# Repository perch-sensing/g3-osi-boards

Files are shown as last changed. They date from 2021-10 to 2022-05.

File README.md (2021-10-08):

# Perch 3GRMC Platform

## Getting Started

You'll want to clone this repo with an `ssh` key. To setup an `ssh` key on
GitHub, follow this [link](https://docs.github.com/en/github/authenticating-to-github/connecting-to-github-with-ssh).

Additionally, this README assumes that you are using Visual Studio Code.

### HW/SW

You need to initialize the various submodules with the following command:

```shell
git submodule update --init --recursive
```

The submodules include the Perch kicad library as well as micropython libraries.

### Hardware

The hardware is designed using KiCad 5.X. You will need to download KiCad from
[https://kicad.org/download/](https://kicad.org/download/).

To work with KiCad files in a Git repository, certain parts of the file should
be ignored. To ignore these commands in git, you can add to the project-local
config. To facilitate this, a `.gitconfig` file has been provided in this
repository. To use the provided `.gitconfig` file, you need to add it to the
project config.

Run the following command:

```shell
git config --local include.path ../.gitconfig
```

Next, you'll want to install `plotkicadsch` to your path. You can download
the binary [here](https://github.com/jnavila/plotkicadsch/releases). For
assistance in adding a folder to your path, visit
[this](https://www.howtogeek.com/118594/how-to-edit-your-system-path-for-easy-command-line-access/) link.

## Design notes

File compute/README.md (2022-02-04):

Here is a link to the Compute BOM:
https://docs.google.com/spreadsheets/d/1j4ZL0j2LjKp-IoZsxxflOpX7Q5H--Hl_RDHMVLFPHzU/edit#gid=0

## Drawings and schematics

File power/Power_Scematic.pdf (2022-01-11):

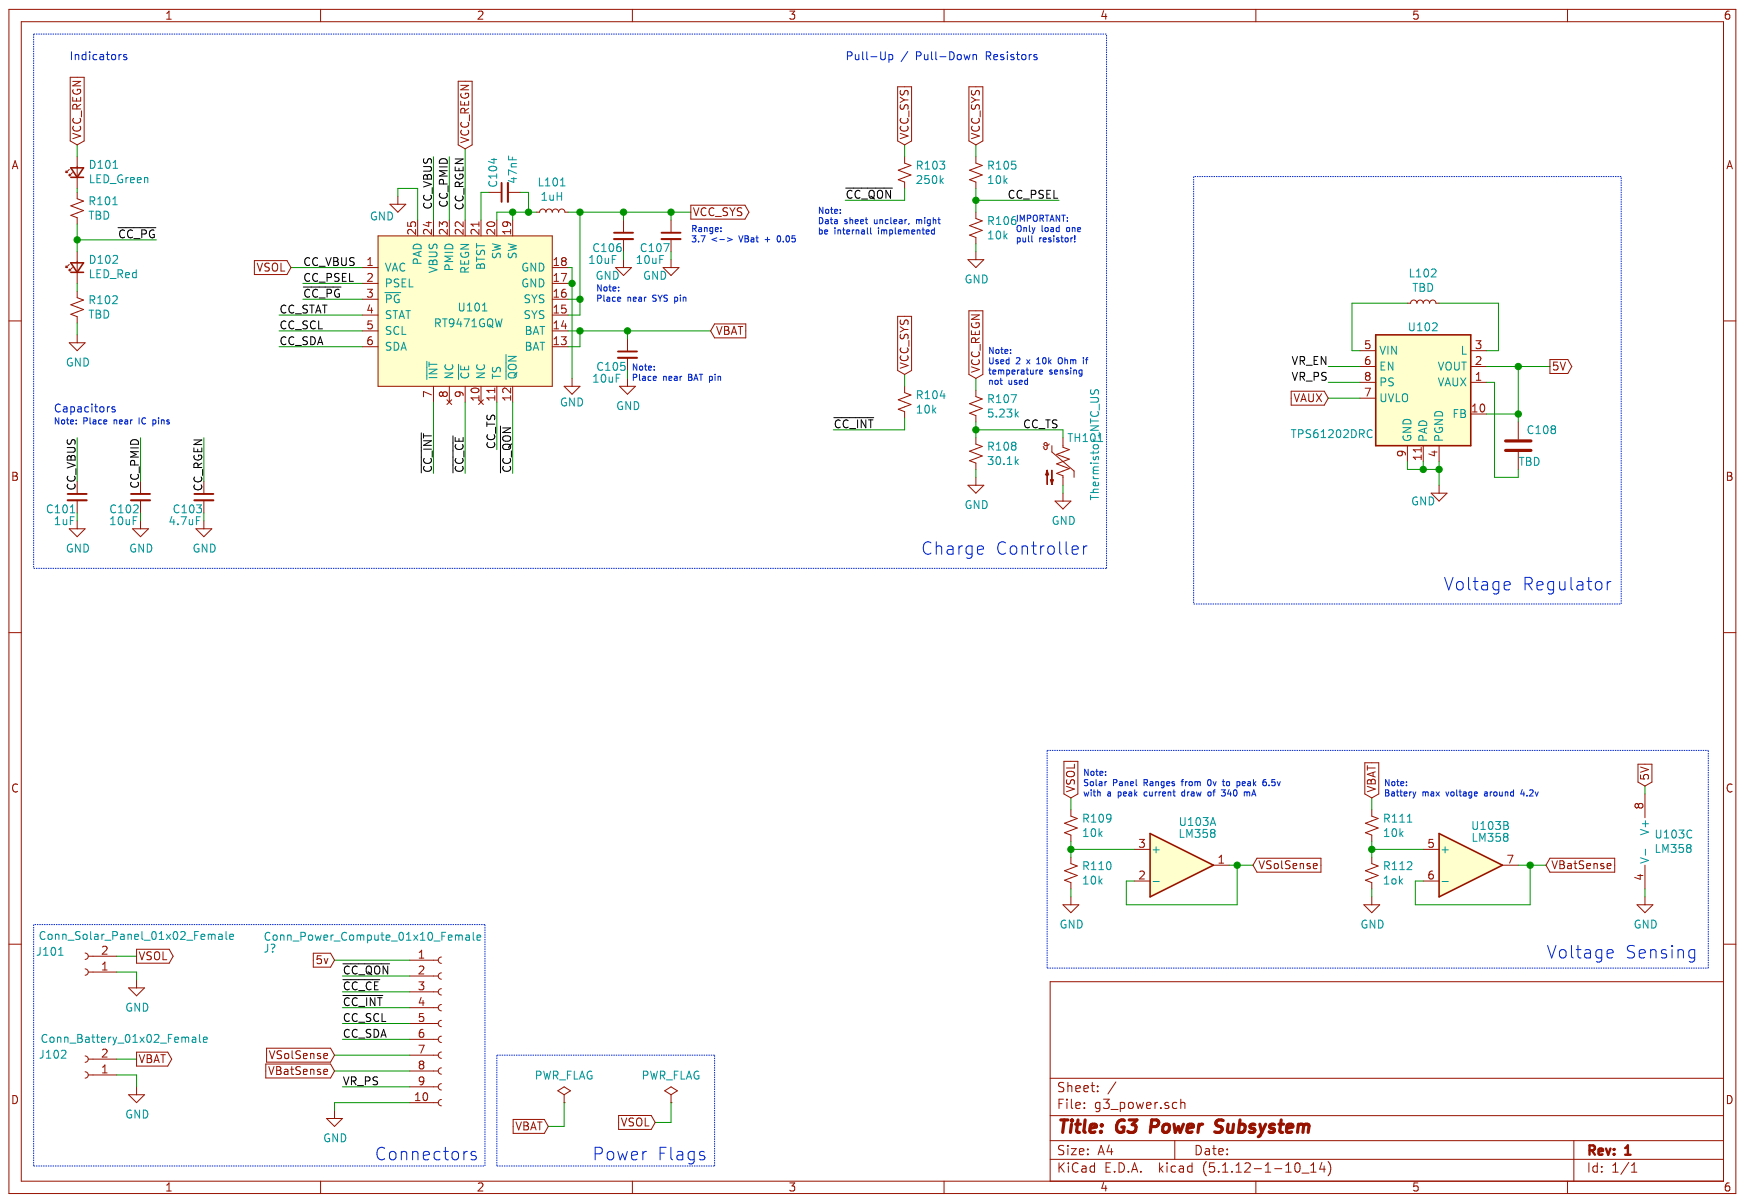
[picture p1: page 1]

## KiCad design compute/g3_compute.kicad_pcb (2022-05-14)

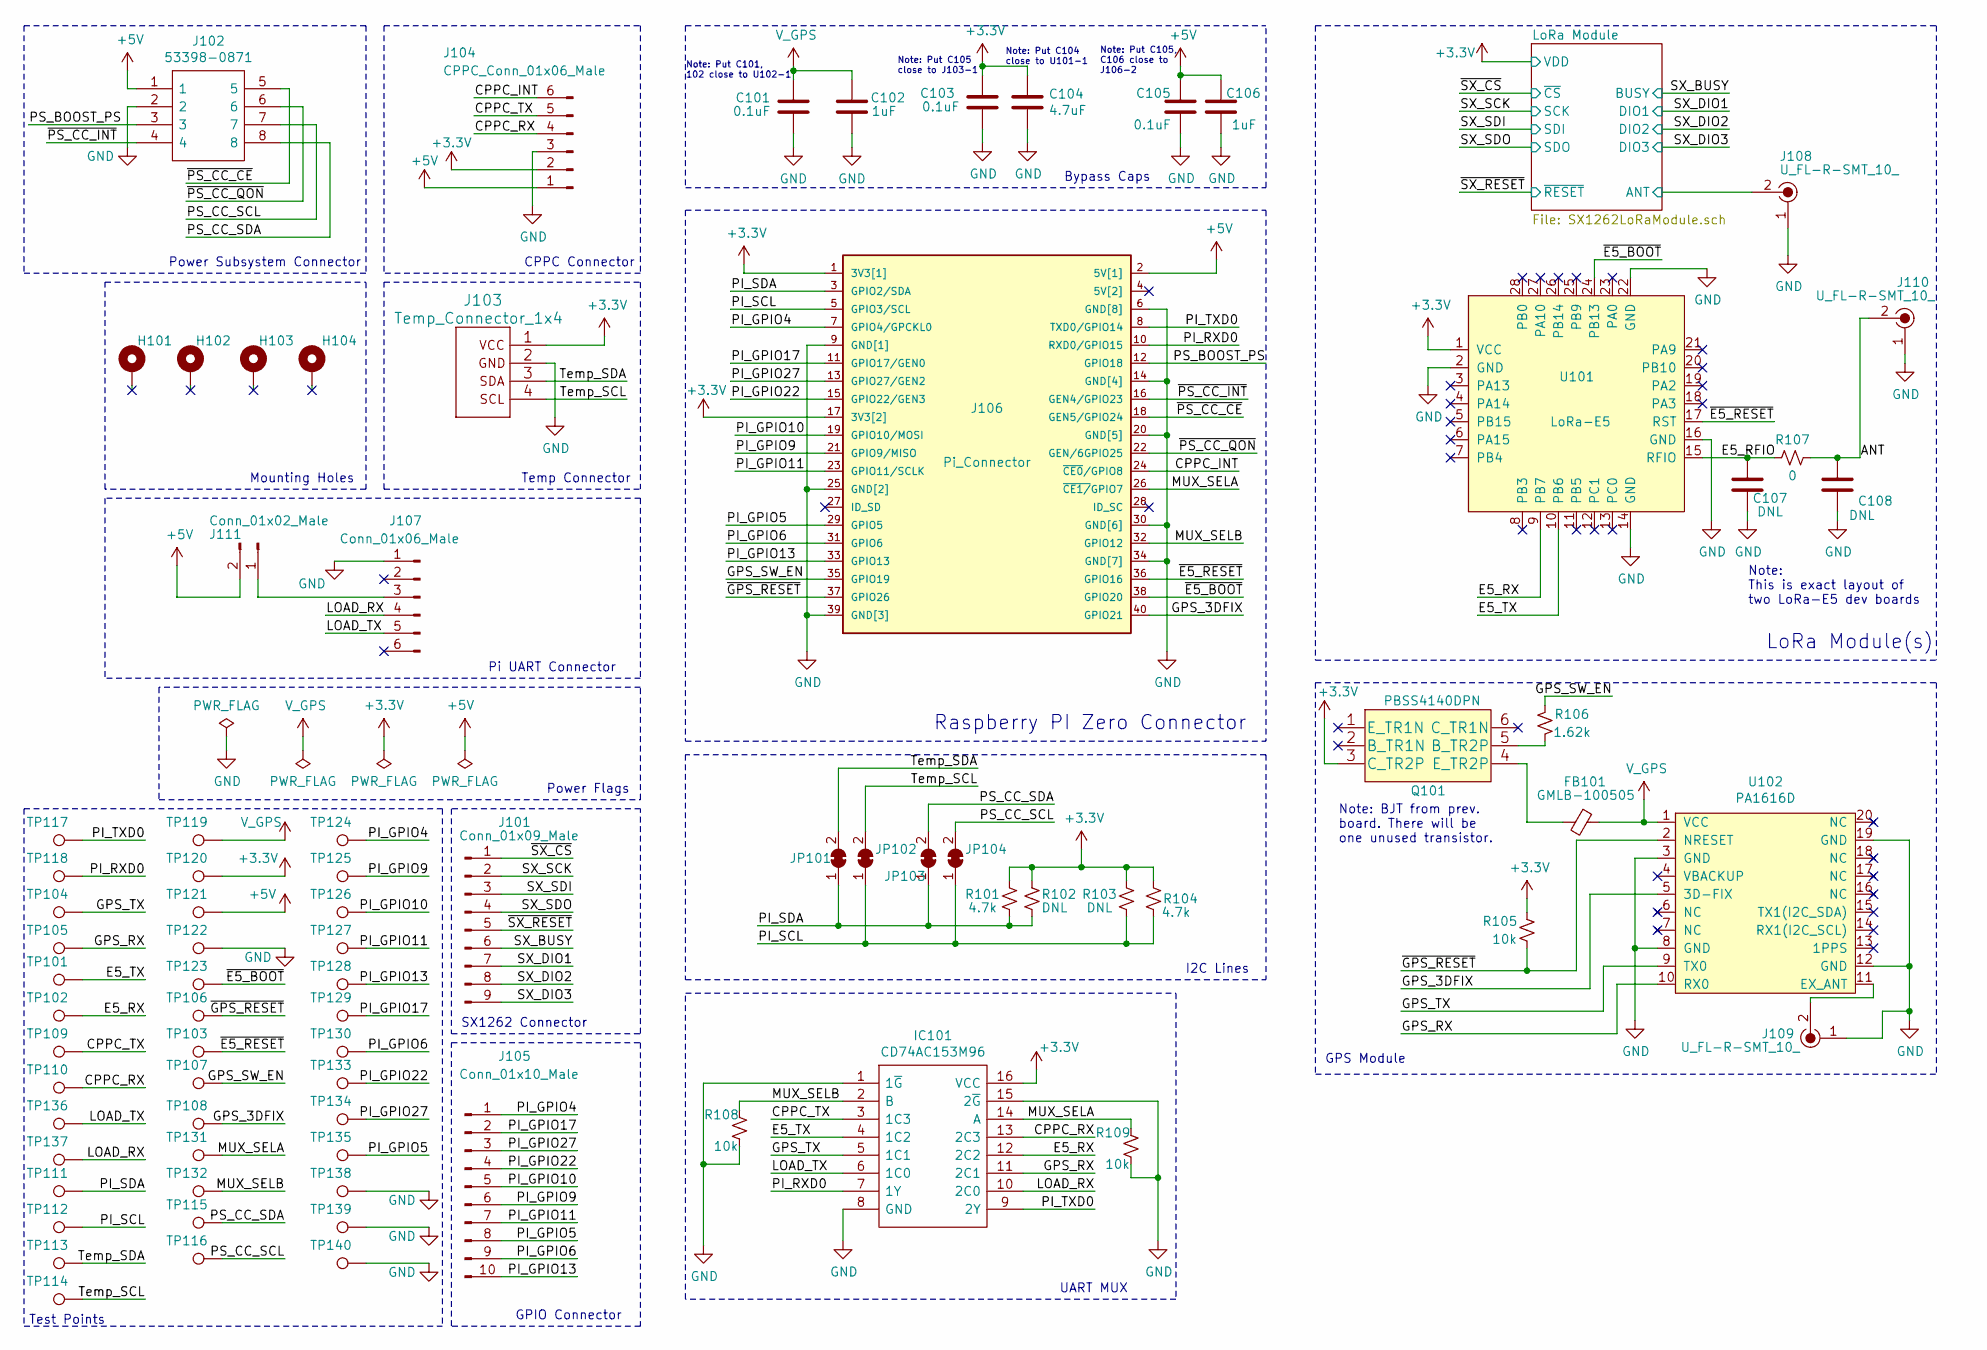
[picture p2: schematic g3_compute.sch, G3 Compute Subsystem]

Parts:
C101, C103, C105: 0.1uF; C_0402_1005Metric_Pad0.74x0.62mm_HandSolder
C102, C106: 1uF; C_0402_1005Metric_Pad0.74x0.62mm_HandSolder
C104: 4.7uF; C_0402_1005Metric_Pad0.74x0.62mm_HandSolder
C107, C108: DNL; C_0402_1005Metric_Pad0.74x0.62mm_HandSolder
FB101: GMLB-100505; R_0402_1005Metric_Pad0.72x0.64mm_HandSolder
H101, H102, H103, H104: MountingHole_Pad; MountingHole_2.5mm_Pad
IC101: CD74AC153M96; SOIC127P600X175-16N_MUX; Mouser Part Number 595-CD74AC153M96
J101: Conn_01x09_Male; PinHeader_1x09_P2.54mm_Vertical
J102: 53398-0871; 53398-0871_Molex
J103: Temp_Connector_1x4; 1702474_Temp_Sensor_Connector
J104: CPPC_Conn_01x06_Male; PinHeader_1x06_P2.54mm_Vertical_SMD_Pin1Left
J105: Conn_01x10_Male; PinHeader_1x10_P2.54mm_Vertical
J106: Pi_Connector; ADA3708_RaspPiZero; Manufacturer_Part_Number 2885
J107: Conn_01x06_Male; PinHeader_1x06_P2.54mm_Vertical
J108, J109, J110: U_FL-R-SMT_10_; Coax_Conn_U.FL; MPN U.FL-R-SMT(10); Digi-Key_PN H9161CT-ND
J111: Conn_01x02_Male; PinHeader_1x02_P2.54mm_Vertical_SMD_Pin1Left
JP101, JP102, JP103, JP104: SolderJumper_2_Bridged; SolderJumper-2_P1.3mm_Bridged_RoundedPad1.0x1.5mm
Q101: PBSS4140DPN
R101, R104: 4.7k; R_0402_1005Metric_Pad0.72x0.64mm_HandSolder
R102, R103: DNL; R_0402_1005Metric_Pad0.72x0.64mm_HandSolder
R105, R108, R109: 10k; R_0402_1005Metric_Pad0.72x0.64mm_HandSolder
R106: 1.62k; R_0603_1608Metric_Pad0.98x0.95mm_HandSolder
R107: 0; R_0402_1005Metric_Pad0.72x0.64mm_HandSolder
TP101, TP102, TP103, TP104, TP105, TP106, TP107, TP108, TP109, TP110, TP111, TP112, TP113, TP114, TP115, TP116, TP117, TP118, TP119, TP120, TP121, TP122, TP123, TP124, TP125, TP126, TP127, TP128, TP129, TP130, TP131, TP132, TP133, TP134, TP135, TP136, TP137, TP138, TP139, TP140: TestPoint; HARWIN_S2751-46R
U101: LoRa-E5
U102: PA1616D; PA1616D_GPS

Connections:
+3V3: C103.2, C104.1, IC101.16 (VCC), J103.1 (Vdd), J104.2, J106.1 (3V3[1]), J106.17 (3V3[2]), Q101.3 (C_TR2P), R101.2, R102.2, R103.2, R104.2, R105.2, TP120.1, U101.1 (VCC); also elsewhere on the board
+5V: C105.2, C106.2, J102.1, J104.1, J106.2 (5V[1]), J111.2, TP121.1
/ANT: C108.1, J110.2, R107.2
/CPPC_INT: J104.6, J106.24 (~CE0~/GPIO8)
/CPPC_RX: IC101.13 (2C3), J104.4, TP110.1
/CPPC_TX: IC101.3 (1C3), J104.5, TP109.1
/E5_RFIO: C107.1, R107.1, U101.15 (RFIO)
/E5_RX: IC101.12 (2C2), TP102.1, U101.9 (PB7)
/E5_TX: IC101.4 (1C2), TP101.1, U101.10 (PB6)
/GPS_3DFIX: J106.40 (GPIO21), TP108.1, U102.5 (3D-FIX)
/GPS_RX: IC101.11 (2C1), TP105.1, U102.10 (RX0)
/GPS_SW_EN: J106.35 (GPIO19), R106.2, TP107.1
/GPS_TX: IC101.5 (1C1), TP104.1, U102.9 (TX0)
/LOAD_RX: IC101.10 (2C0), J107.4, TP137.1
/LOAD_TX: IC101.6 (1C0), J107.5, TP136.1
/LoRa Module/ANT: J108.2; also elsewhere on the board
/MUX_SELA: IC101.14 (A), J106.26 (~CE1/~GPIO7), R109.2, TP131.1
/MUX_SELB: IC101.2 (B), J106.32 (GPIO12), R108.2, TP132.1
/PI_GPIO4: J105.1, J106.7 (GPIO4/GPCKL0), TP124.1
/PI_GPIO5: J105.8, J106.29 (GPIO5), TP135.1
/PI_GPIO6: J105.9, J106.31 (GPIO6), TP130.1
/PI_GPIO9: J105.6, J106.21 (GPIO9/MISO), TP125.1
/PI_GPIO10: J105.5, J106.19 (GPIO10/MOSI), TP126.1
/PI_GPIO11: J105.7, J106.23 (GPIO11/SCLK), TP127.1
/PI_GPIO13: J105.10, J106.33 (GPIO13), TP128.1
/PI_GPIO17: J105.2, J106.11 (GPIO17/GEN0), TP129.1
/PI_GPIO22: J105.4, J106.15 (GPIO22/GEN3), TP133.1
/PI_GPIO27: J105.3, J106.13 (GPIO27/GEN2), TP134.1
/PI_RXD0: IC101.7 (1Y), J106.10 (RXD0/GPIO15), TP118.1
/PI_SCL: J106.5 (GPIO3/SCL), JP102.1 (A), JP104.1 (A), R103.1, R104.1, TP112.1
/PI_SDA: J106.3 (GPIO2/SDA), JP101.1 (A), JP103.1 (A), R101.1, R102.1, TP111.1
/PI_TXD0: IC101.9 (2Y), J106.8 (TXD0/GPIO14), TP117.1
/PS_BOOST_PS: J102.3, J106.12 (GPIO18)
/PS_CC_SCL: J102.7, JP104.2 (B), TP116.1
/PS_CC_SDA: J102.8, JP103.2 (B), TP115.1
/SX_BUSY: J101.6; also elsewhere on the board
/SX_DIO1: J101.7; also elsewhere on the board
/SX_DIO2: J101.8; also elsewhere on the board
/SX_DIO3: J101.9; also elsewhere on the board
/SX_SCK: J101.2; also elsewhere on the board
/SX_SDI: J101.3; also elsewhere on the board
/SX_SDO: J101.4; also elsewhere on the board
/Temp_SCL: J103.4 (SCL), JP102.2 (B), TP114.1
/Temp_SDA: J103.3 (SDA), JP101.2 (B), TP113.1
/~E5_BOOT: J106.38 (GPIO20), TP123.1, U101.24 (PB13~)
/~E5_RESET: J106.36 (GPIO16), TP103.1, U101.17 (RST)
/~GPS_RESET: J106.37 (GPIO26), R105.1, TP106.1, U102.2 (NRESET)
/~PS_CC_CE: J102.5, J106.18 (GEN5/GPIO24)
/~PS_CC_INT: J102.4, J106.16 (GEN4/GPIO23)
/~PS_CC_QON: J102.6, J106.22 (GEN/6GPIO25)
/~SX_CS: J101.1; also elsewhere on the board
/~SX_RESET: J101.5; also elsewhere on the board
GND: C101.1, C102.1, C103.1, C104.2, C105.1, C106.1, C107.2, C108.2, IC101.1 (1~G), IC101.8 (GND), IC101.15 (2~G), J102.2, J103.2 (Gnd), J104.3, J106.6 (GND[8]), J106.9 (GND[1]), J106.14 (GND[4]), J106.20 (GND[5]), J106.25 (GND[2]), J106.30 (GND[6]), J106.34 (GND[7]), J106.39 (GND[3]), J107.1, J108.1, J109.1, J110.1, R108.1, R109.1, TP122.1, TP138.1, TP139.1, TP140.1, U101.2 (GND), U101.14 (GND), U101.16 (GND), U101.22 (GND), U102.3 (GND), U102.8 (GND), U102.12 (GND), U102.19 (GND); also elsewhere on the board
unnamed: FB101.2, Q101.4 (E_TR2P)
unnamed: J107.3, J111.1
unnamed: J109.2, U102.11 (EX_ANT)
unnamed: Q101.5 (B_TR2P), R106.1
V_GPS: C101.2, C102.2, FB101.1, TP119.1, U102.1 (VCC)

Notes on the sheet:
Power Subsystem Connector
Mounting Holes
SX1262 Connector
GPIO Connector
GPS Module
Note: BJT from prev. board. There will be one unused transistor.
Note: This is exact layout of two LoRa-E5 dev boards
Note: Put C101, 102 close to U102-1
Note: Put C105 close to J103-1
Pi UART Connector
Note: Put C105, C106 close to J106-2
Bypass Caps
Raspberry PI Zero Connector
LoRa Module(s)
Temp Connector
CPPC Connector
I2C Lines
Test Points
UART MUX
Power Flags
Note: Put C104 close to U101-1

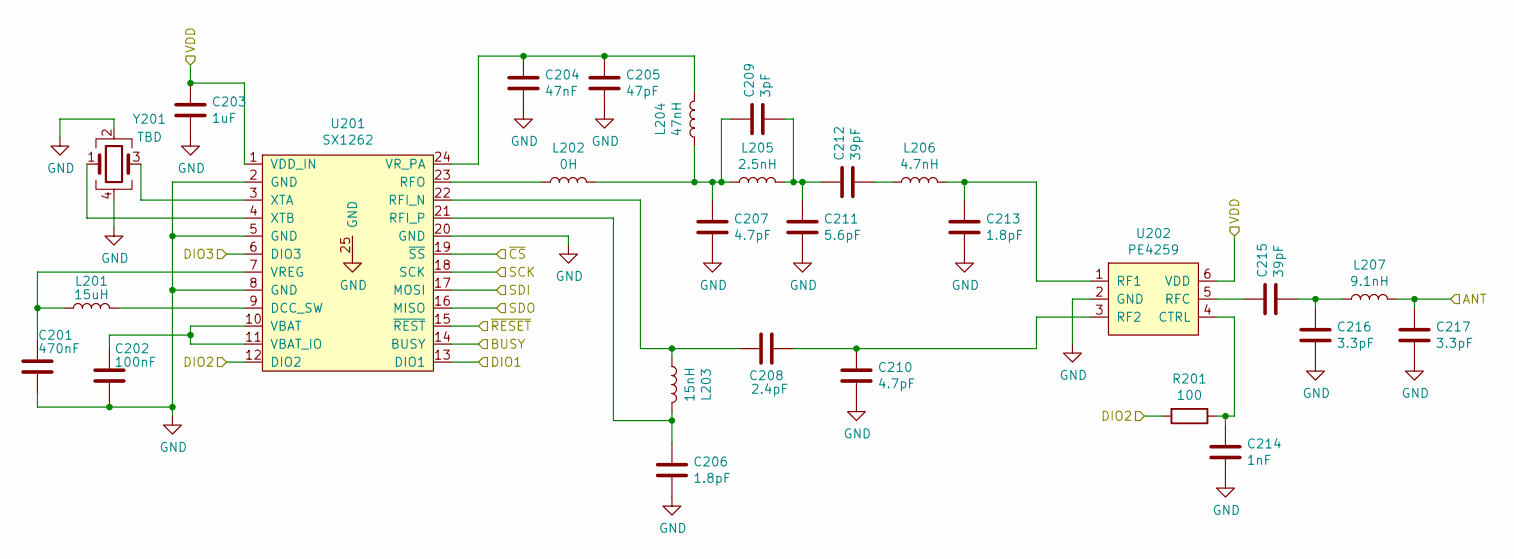
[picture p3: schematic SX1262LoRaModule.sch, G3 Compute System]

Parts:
C201: 470nF; C_0402_1005Metric_Pad0.74x0.62mm_HandSolder
C202: 100nF; C_0402_1005Metric_Pad0.74x0.62mm_HandSolder
C203: 1uF; C_0402_1005Metric_Pad0.74x0.62mm_HandSolder
C204: 47nF; C_0402_1005Metric_Pad0.74x0.62mm_HandSolder
C205: 47pF; C_0402_1005Metric_Pad0.74x0.62mm_HandSolder
C206, C213: 1.8pF; C_0402_1005Metric_Pad0.74x0.62mm_HandSolder
C207, C210: 4.7pF; C_0402_1005Metric_Pad0.74x0.62mm_HandSolder
C208: 2.4pF; C_0402_1005Metric_Pad0.74x0.62mm_HandSolder
C209: 3pF; C_0402_1005Metric_Pad0.74x0.62mm_HandSolder
C211: 5.6pF; C_0402_1005Metric_Pad0.74x0.62mm_HandSolder
C212, C215: 39pF; C_0402_1005Metric_Pad0.74x0.62mm_HandSolder
C214: 1nF; C_0402_1005Metric_Pad0.74x0.62mm_HandSolder
C216, C217: 3.3pF; C_0402_1005Metric_Pad0.74x0.62mm_HandSolder
L201: 15uH; L_0805_2012Metric_Pad1.05x1.20mm_HandSolder
L202: 0H; L_0402_1005Metric_Pad0.77x0.64mm_HandSolder
L203: 15nH; L_0402_1005Metric_Pad0.77x0.64mm_HandSolder
L204: 47nH; L_0402_1005Metric_Pad0.77x0.64mm_HandSolder
L205: 2.5nH; L_0402_1005Metric_Pad0.77x0.64mm_HandSolder
L206: 4.7nH; L_0402_1005Metric_Pad0.77x0.64mm_HandSolder
L207: 9.1nH; L_0402_1005Metric_Pad0.77x0.64mm_HandSolder
R201: 100; R_0402_1005Metric_Pad0.72x0.64mm_HandSolder
U201: SX1262; QFN-24-1EP_4x4mm_P0.5mm_EP2.7x2.7mm
U202: PE4259; SOT-363_SC-70-6
Y201: TBD; Crystal_SMD_2016-4Pin_2.0x1.6mm

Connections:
+3V3: C203.1, U201.1 (VDD_IN), U202.6 (VDD); also elsewhere on the board
/LoRa Module/ANT: C217.1, L207.2; also elsewhere on the board
/SX_BUSY: U201.14 (BUSY); also elsewhere on the board
/SX_DIO1: U201.13 (DIO1); also elsewhere on the board
/SX_DIO2: R201.2, U201.12 (DIO2); also elsewhere on the board
/SX_DIO3: U201.6 (DIO3); also elsewhere on the board
/SX_SCK: U201.18 (SCK); also elsewhere on the board
/SX_SDI: U201.17 (MOSI); also elsewhere on the board
/SX_SDO: U201.16 (MISO); also elsewhere on the board
/~SX_CS: U201.19 (~SS); also elsewhere on the board
/~SX_RESET: U201.15 (~REST); also elsewhere on the board
GND: C201.2, C202.2, C203.2, C204.2, C205.2, C206.2, C207.2, C210.2, C211.2, C213.2, C214.2, C216.2, C217.2, U201.2 (GND), U201.5 (GND), U201.8 (GND), U201.20 (GND), U201.25 (GND), U202.2 (GND), Y201.2, Y201.4; also elsewhere on the board
unnamed: C201.1, L201.1, U201.7 (VREG)
unnamed: C202.1, U201.10 (VBAT), U201.11 (VBAT_IO)
unnamed: C204.1, C205.1, L204.2, U201.24 (VR_PA)
unnamed: C206.1, L203.2, U201.21 (RFI_P)
unnamed: C207.1, C209.1, L202.2, L204.1, L205.1
unnamed: C208.1, L203.1, U201.22 (RFI_N)
unnamed: C208.2, C210.1, U202.3 (RF2)
unnamed: C209.2, C211.1, C212.1, L205.2
unnamed: C212.2, L206.1
unnamed: C213.1, L206.2, U202.1 (RF1)
unnamed: C214.1, R201.1, U202.4 (CTRL)
unnamed: C215.1, U202.5 (RFC)
unnamed: C215.2, C216.1, L207.1
unnamed: L201.2, U201.9 (DCC_SW)
unnamed: L202.1, U201.23 (RFO)
unnamed: U201.3 (XTA), Y201.3
unnamed: U201.4 (XTB), Y201.1

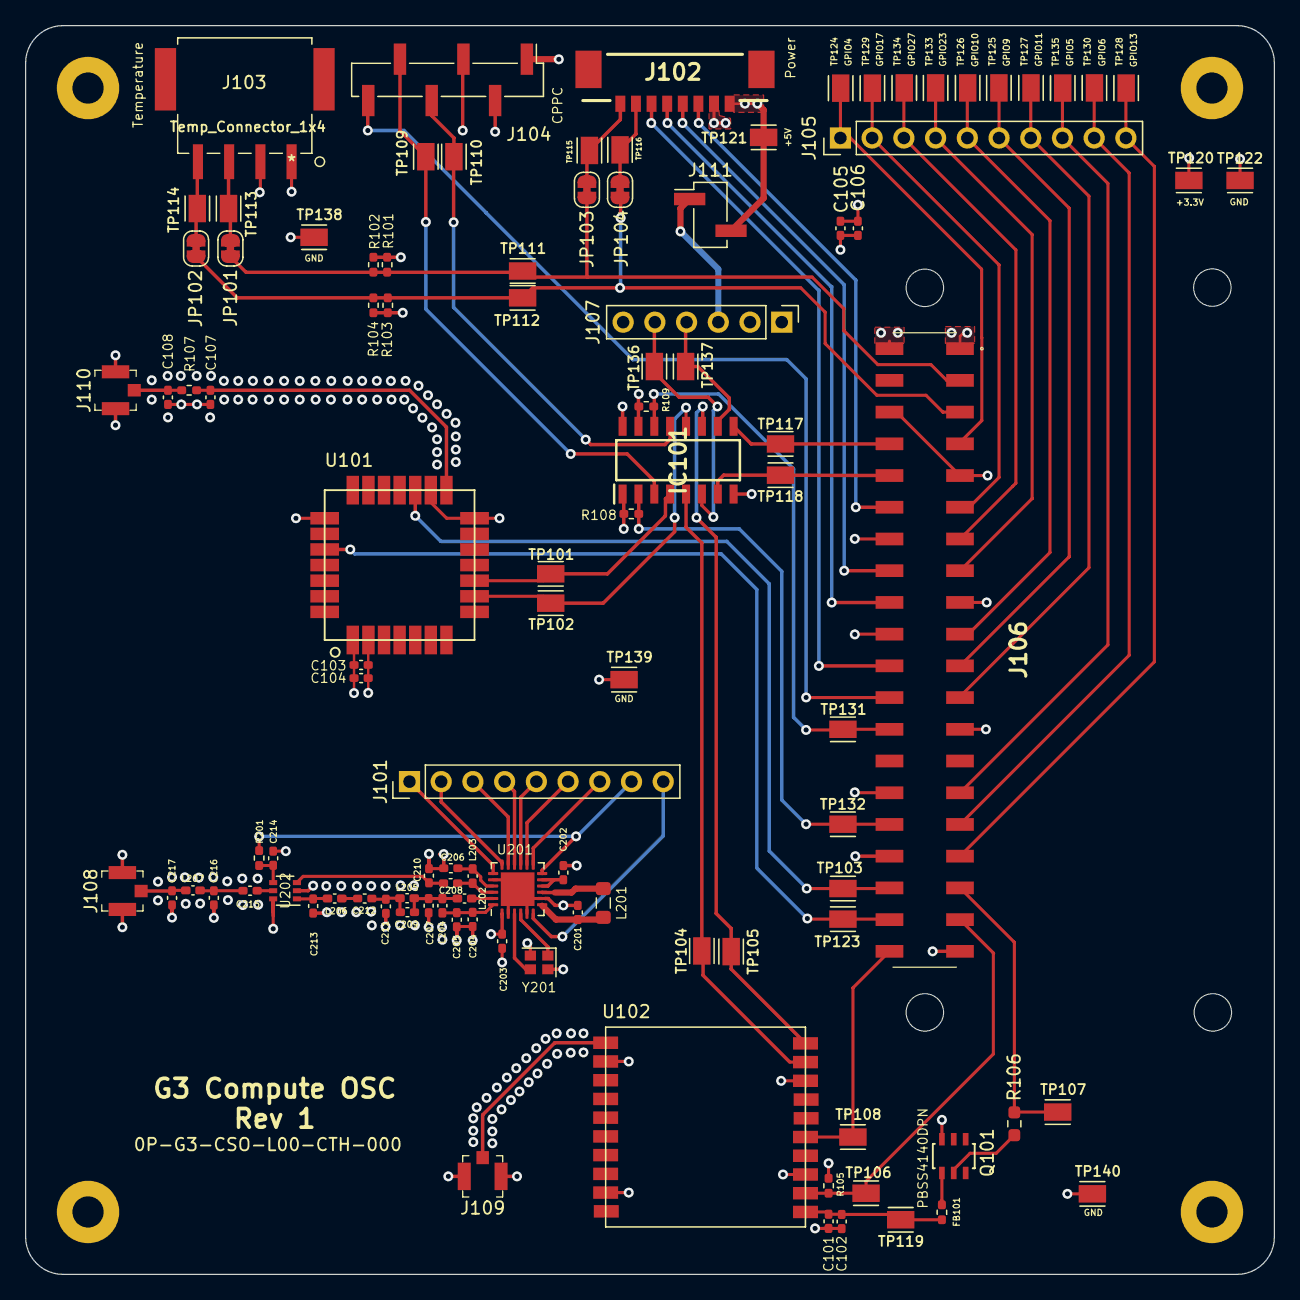
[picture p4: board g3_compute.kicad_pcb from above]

Board: 4 copper layers, 100.0 x 100.0 mm, 109 parts (0 on the bottom side), 75 nets.

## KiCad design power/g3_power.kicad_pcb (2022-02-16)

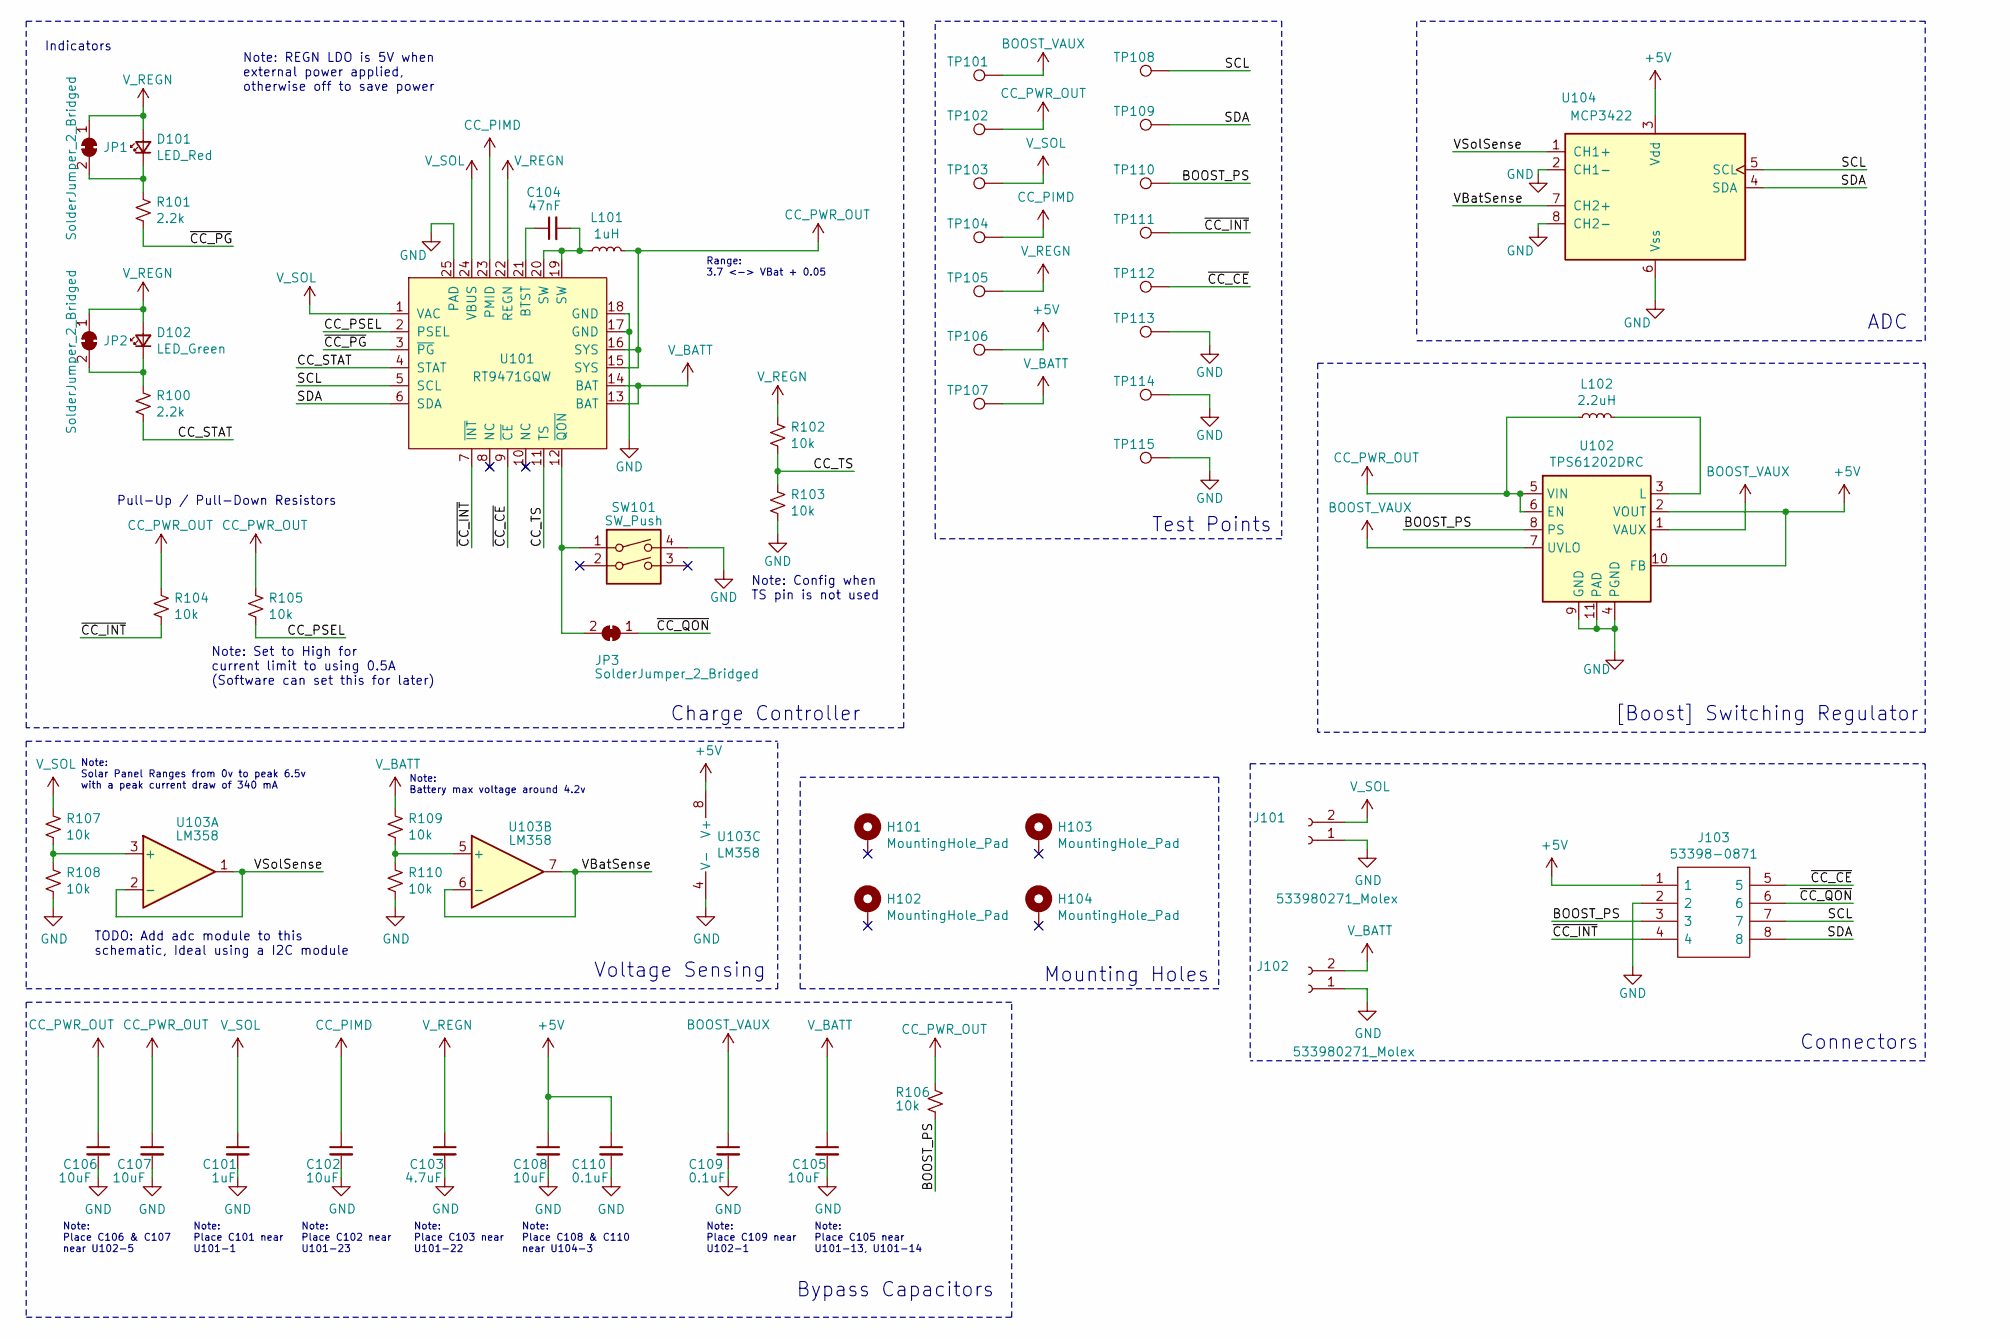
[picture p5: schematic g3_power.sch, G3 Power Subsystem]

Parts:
C101: 1uF; C_0402_1005Metric_Pad0.74x0.62mm_HandSolder; Manufacturer_Part_Number CC0402MRX5R6BB105
C102, C105, C106, C107, C108: 10uF; C_0402_1005Metric_Pad0.74x0.62mm_HandSolder; Manufacturer_Part_Number CAP CER 10000PF 16V X7R 0402
C103: 4.7uF; C_0402_1005Metric_Pad0.74x0.62mm_HandSolder; Manufacturer_Part_Number CC0402MRX5R6BB475
C104: 47nF; C_0805_2012Metric_Pad1.18x1.45mm_HandSolder; Manufacturer_Part_Number CL21B473KCCWPNC
C109, C110: 0.1uF; C_0402_1005Metric_Pad0.74x0.62mm_HandSolder; Manufacturer_Part_Number CC0402JRX7R7BB104
D101: LED_Red; LED_0402_1005Metric_Pad0.77x0.64mm_HandSolder; Manufacturer_Part_Number SML-LX0402SIC-TR
D102: LED_Green; LED_0402_1005Metric_Pad0.77x0.64mm_HandSolder; Manufacturer_Part_Number SML-LX0402SUGC-TR
H101, H102, H103, H104: MountingHole_Pad; MountingHole_2.5mm_Pad
J101, J102: 533980271_Molex; 532610271_Molex; Manufacturer_Part_Number 532610271
J103: 53398-0871; 53398-0871_Molex; Mouser Part Number 538-53398-0871
JP1, JP2, JP3: SolderJumper_2_Bridged; SolderJumper-2_P1.3mm_Bridged_RoundedPad1.0x1.5mm
L101: 1uH; L_1008_2520Metric_Pad1.43x2.20mm_HandSolder; Manufacturer_Part_Number CIGT252010LM1R0MNE
L102: 2.2uH; L_0805_2012Metric_Pad1.15x1.40mm_HandSolder; Manufacturer_Part_Number CIGT201610LH2R2MNE
R100, R101: 2.2k; R_0402_1005Metric_Pad0.72x0.64mm_HandSolder; Manufacturer_Part_Number RC0402JR-072K2L
R102, R103, R104, R105, R106, R107, R108, R109, R110: 10k; R_0402_1005Metric_Pad0.72x0.64mm_HandSolder; Manufacturer_Part_Number RC0402JR-0710KL
SW101: SW_Push; Switch_Tactile_SMD_6x6mm_PTS645; Manufacturer_Part_Number PTS645SH43SMTR92 LFS
TP101, TP102, TP103, TP104, TP105, TP106, TP107, TP108, TP109, TP110, TP111, TP112, TP113, TP114, TP115: TestPoint; HARWIN_S2751-46R
U101: RT9471GQW; WQFN-24-1EP_4x4mm_P0.5mm_EP2.6x2.6mm_ThermalVias; Manufacturer_Part_Number RT9471GQW(2)
U102: TPS61202DRC; VSON-10-1EP_3x3mm; Manufacturer_Part_Number TPS61202DRCT
U103: LM358; SOIC-8_3.9x4.9mm_P1.27mm; Manufacturer_Part_Number LM358D
U104: MCP3422; SOIC-8_3.9x4.9mm_P1.27mm; Manufacturer_Part_Number MCP3422A1T-E/SN

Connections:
+5V: C108.1, C110.1, J103.1, TP106.1, U102.2 (VOUT), U102.10 (FB), U103.8 (V+), U104.3 (Vdd)
/BOOST_PS: J103.3, R106.2, TP110.1, U102.8 (PS)
/CC_PSEL: R105.2, U101.2 (PSEL)
/CC_STAT: R100.2, U101.4 (STAT)
/CC_TS: R102.2, R103.1, U101.11 (TS)
/SCL: J103.7, TP108.1, U101.5 (SCL), U104.5 (SCL)
/SDA: J103.8, TP109.1, U101.6 (SDA), U104.4 (SDA)
/VBatSense: U103.6 (-), U103.7, U104.7 (CH2+)
/VSolSense: U103.1, U103.2 (-), U104.1 (CH1+)
/~CC_CE: J103.5, TP112.1, U101.9 (~CE)
/~CC_INT: J103.4, R104.2, TP111.1, U101.7 (~INT)
/~CC_PG: R101.2, U101.3 (~PG)
/~CC_QON: J103.6, JP3.1 (A)
BOOST_VAUX: C109.1, TP101.1, U102.1 (VAUX), U102.7 (UVLO)
CC_PIMD: C102.1, TP104.1, U101.23 (PMID)
CC_PWR_OUT: C106.1, C107.1, L101.2, L102.1, R104.1, R105.1, R106.1, TP102.1, U101.15 (SYS), U101.16 (SYS), U102.5 (VIN), U102.6 (EN)
GND: C101.2, C102.2, C103.2, C105.2, C106.2, C107.2, C108.2, C109.2, C110.2, J101.1, J102.1, J103.2, R103.2, R108.2, R110.2, SW101.4, TP113.1, TP114.1, TP115.1, U101.17 (GND), U101.18 (GND), U101.25 (PAD), U102.4 (PGND), U102.9 (GND), U102.11 (PAD), U103.4 (V-), U104.2 (CH1-), U104.6 (Vss), U104.8 (CH2-)
unnamed: C104.1, U101.21 (BTST)
unnamed: C104.2, L101.1, U101.19 (SW), U101.20 (SW)
unnamed: D101.1 (K), JP1.2 (B), R101.1
unnamed: D102.1 (K), JP2.2 (B), R100.1
unnamed: JP3.2 (B), SW101.1, U101.12 (~QON)
unnamed: L102.2, U102.3 (L)
unnamed: R107.2, R108.1, U103.3 (+)
unnamed: R109.2, R110.1, U103.5 (+)
V_BATT: C105.1, J102.2, R109.1, TP107.1, U101.13 (BAT), U101.14 (BAT)
V_REGN: C103.1, D101.2 (A), D102.2 (A), JP1.1 (A), JP2.1 (A), R102.1, TP105.1, U101.22 (REGN)
V_SOL: C101.1, J101.2, R107.1, TP103.1, U101.1 (VAC), U101.24 (VBUS)

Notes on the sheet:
Connectors
[Boost] Switching Regulator
Note: Solar Panel Ranges from 0v to peak 6.5v with a peak current draw of 340 mA
Voltage Sensing
Note: Battery max voltage around 4.2v
TODO: Add adc module to this schematic, Ideal using a I2C module
Note: Set to High for current limit to using 0.5A (Software can set this for later)
Note: REGN LDO is 5V when external power applied, otherwise off to save power
Range: 3.7 <-> VBat + 0.05
Pull-Up / Pull-Down Resistors
Indicators
ADC
Note: Place C106 & C107 near U102-5
Note: Place C109 near U102-1
Note: Place C105 near U101-13, U101-14
Note: Place C108 & C110 near U104-3
Charge Controller
Note: Place C102 near U101-23
Note: Place C101 near U101-1
Note: Place C103 near U101-22
Bypass Capacitors
Note: Config when TS pin is not used
Mounting Holes
Test Points

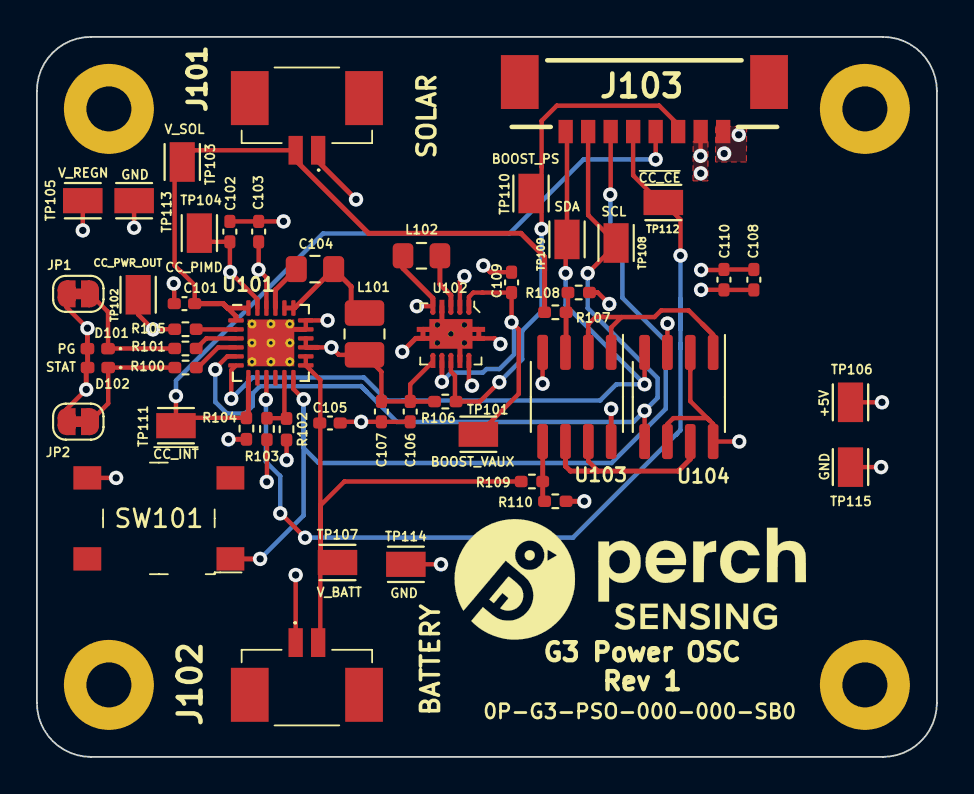
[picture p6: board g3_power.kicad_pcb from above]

Board: 4 copper layers, 50.0 x 40.0 mm, 55 parts (1 on the bottom side), 28 nets.

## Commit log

2021-10-02 add initial project files
    [g3_compute.kicad_pcb, g3_compute.sch, g3_power.kicad_pcb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]
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2021-11-15 added GPS and PI to schematic
    [LoRaModule.sch, g3_compute.sch]
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2021-11-15 added temp sensor to schematic
    [g3_compute.sch]
2021-11-15 Testing collisions
    [g3_compute.sch]
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2021-11-17 test - added LoRa to sch
    [g3_compute.sch]
2021-11-21 Updating schematic and began routing LoRa module
    [LoRaModule.sch, g3_compute.kicad_pcb, g3_compute.sch]
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2021-11-22 Added interfacing to GPS Module
    [LoRaModule.sch, g3_compute.sch]
2021-11-22 added Temp connector interfacing
    [g3_compute.sch]
2021-11-22 added some connections from PI to LoRa module
    [g3_compute.sch]
2021-11-24 added extra field values to modules in schematic to help with BOM managment
    [g3_compute.sch]
2021-11-26 changed up wiring in schematic
    [g3_compute.sch]
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2021-11-29 Fixing libraries and schematic ref nums
    [GPS_Switch.sch, LoRaModule.sch, g3_compute.kicad_pcb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]
2021-11-29 added temperature sensor interfacing and changed page layout path
    [g3_compute.kicad_pcb, g3_compute.sch]
2021-11-30 Wiring pi pins to modules
    [g3_compute.sch]
2021-12-01 added appropriate custom fields to GPS, MPU, and Temp connector for BOM use
    [g3_compute.sch]
2021-12-01 added appropriate custom fields to GPS, MPU, and Temp connector for BOM usage
    [g3_compute.sch]
2021-12-03 added 470ohm resistors fields to BOM
    [g3_compute.sch]
2021-12-03 Added fields for 4.7uF and 470nF capacitors
    [LoRaModule.sch, g3_compute.sch]
2021-12-03 added 47nF and 100nF capacitor fields
    [LoRaModule.sch]
2021-12-15 added charge controller and switching regulator symbols to schematic
    [g3_power.sch]
2021-12-15 added interfacing to charge controller on schematic
    [g3_power.sch]
2021-12-15 added VR interfacing on schematic
    [g3_power.sch]
2021-12-15 small changes to VR interfacing
    [g3_power.sch]
2021-12-15 added fields for power BOM
    [g3_power.sch]
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2021-12-22 small changes to power schematic layout
    [g3_power.sch]
2021-12-22 referenced charge controller footprint in schematic
    [g3_power.sch]
2021-12-22 updated compute schematic with test points and UART connections
    [g3_compute.sch]
2021-12-22 added remaining GPIO on PI to a header
    [g3_compute.sch]
2021-12-22 rework on sch and layout
    [g3_compute.kicad_pcb, g3_compute.sch]
2021-12-22 Mering in LoRa BOM field changes
    [GPS_Switch.sch, LoRaModule.sch]
2021-12-22 BOM fields changes to LoRa module
    [g3_compute.sch]
2021-12-22 Adding Power Subsystem connector
    [GPS_Switch.sch, g3_compute.sch]
2021-12-23 test points, footprints fixes, and layout fixes
    [GPS_Switch.sch, g3_compute.kicad_pcb, g3_compute.sch]
2021-12-26 Finishing Charge Controller Implementation
    [SX1262LoRaModule.sch, g3_compute.sch, g3_power.sch]
2021-12-28 Updating Power subsystem BOM fields and board to board connector
    [g3_compute.sch, g3_power.sch]
2022-01-05 Adding Power to compute connector
    [g3_compute.sch]
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2022-01-05 Adjusting connectors foot prints
    [g3_compute.kicad_pcb, g3_compute.sch]
2022-01-05 First preliminary layout of pcb
    [g3_compute.kicad_pcb]
2022-01-10 Mapping Power systems signals to pi
    [g3_compute.sch]
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2022-01-11 fixes to power and compute
    [GPS_Switch.sch, g3_compute.kicad_pcb, g3_compute.sch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]
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2022-01-11 Updated BOM on compute subsystem
    [GPS_Switch.sch, g3_compute.sch]
2022-01-11 some more updates to compute BOM
    [GPS_Switch.sch, g3_compute.sch]
2022-01-11 Changed connectors symbols to be molex connectors
    [g3_compute.sch]
2022-01-11 Some small updates to molex symbols
    [g3_compute.sch]
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2022-01-12 Removed GPS_Switch sheet, changed symbol for all resistors on compute schematic
    [g3_compute.sch]
2022-01-12 Major changes to Power sch
    [g3_power.sch]
2022-01-12 Various changes to compute schematic given by Perch feedback
    [g3_compute.sch]
2022-01-13 More changes to compute schematic given by perch feedback
    [g3_compute.sch]
2022-01-14 several more changes to compute schematic
    [g3_compute.sch]
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2022-01-20 added some minor changes according to Perch feedback
    [g3_compute.sch]
2022-01-20 Made NC pins more consistent on compute schematic
    [g3_compute.sch]
2022-01-21 Removed UART Resitors, Fixed I2C pull up resistors, changed Pi UART Connector to standard male header
    [g3_compute.sch]
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2022-01-21 Changed out the two molex connectors to what is wanted in the feedback
    [g3_compute.sch]
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2022-01-27 Changed to revision 4 and made I2C pullup resisotrs 4.7k
    [SX1262LoRaModule.sch, g3_compute.sch]
2022-01-27 Added E5s PB13 pin as E5_BOOT and connected it to a GPIO, also changed the GPIO header to 6 pins instead of 7
    [g3_compute.sch]
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2022-01-27 Moved schematic around to make room for mux, also placed mux
    [g3_compute.sch]
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2022-01-27 Fix GPIO connector
    [g3_compute.sch]
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2022-01-31 Moved all parts around for PCB layout except second LoRa module
    [g3_compute.kicad_pcb]
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2022-02-02 Changed pinout to GPIO Connector to make routing easier
    [g3_compute.kicad_pcb, g3_compute.sch]
2022-02-02 Changed pinnout of UART MUX to make routing easier
    [g3_compute.kicad_pcb, g3_compute.sch]
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2022-02-02 Routed all of the connectors except for backup LoRa
    [g3_compute.kicad_pcb, g3_compute.sch]
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2022-02-02 Filled all zones for power and ground planes
    [g3_compute.kicad_pcb]
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2022-02-04 Revert "Adding more GND testpoints"
    This reverts commit 458bd6481f51bde2da150f265f3cf5d6fabf7a4a.
    [SX1262LoRaModule.sch, g3_compute.kicad_pcb, g3_compute.sch]
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2022-02-04 Adding waveguides and note to compute RF signals
    [g3_compute.kicad_pcb]
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2022-02-08 Changed Pi Connectors field values and added more values to two pin connector
    [SX1262LoRaModule.sch, g3_compute.sch]
2022-02-08 fixes to schematic and layout
    [g3_power.kicad_pcb, g3_power.sch]
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2022-02-10 Fixing fab layers and stray trace
    [g3_power.kicad_pcb]
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2022-02-15 U.FL replacement as well as CPPC connector
    [g3_compute.kicad_pcb, g3_compute.sch]
2022-02-15 Fixing exclude regions
    [g3_compute.kicad_pcb]
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2022-03-15 Flipped GPS switch to use PNP BJT
    [SX1262LoRaModule.sch, g3_compute.kicad_pcb, g3_compute.sch]
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

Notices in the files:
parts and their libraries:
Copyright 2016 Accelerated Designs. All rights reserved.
